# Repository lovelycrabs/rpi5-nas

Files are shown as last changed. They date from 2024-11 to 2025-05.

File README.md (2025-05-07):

## Installation
1.config system
```shell
git clone https://github.com/lovelycrabs/rpi5-nas.git
cd rpi5-nas
sudo chmod +x install.sh
sudo ./install.sh
sudo reboot
```
3.5寸4盘位RPI5_NAS_H4需要修改/boot/firmware/config.txt,该版本的风扇支持二线、三线、四线通用风扇、pwm风扇的周期改成20000000ns即频率为50hz
sudo nano /boot/firmware/config.txt
```shell
dtoverlay=pwm-fan-lm75,period=20000000
```
[overlay配置说明](boot/firmware/overlays)

可以通过下面命令查看系统功率
```shell
cat /sys/class/i2c-adapter/i2c-1/1-0040/hwmon/hwmon*/power1_input
```

查看输入电压
```shell
cat /sys/class/i2c-adapter/i2c-1/1-0040/hwmon/hwmon*/in1_input
```

查看lm75温度
```shell
cat /sys/class/i2c-adapter/i2c-1/1-0048/hwmon/hwmon*/temp1_input
```

2.install spi oled service
```shell
cd rpi5-nas/utils/display
sudo ./install.sh
```

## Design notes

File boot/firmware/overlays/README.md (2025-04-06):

## overlays配置
### 1，pwm-fan 配置
dts编译：
```shell
dtc -I dts -O dtb -o pwm-fan-lm75.dtbo pwm-fan-lm75.dts
dtc -I dts -O dtb -o pwm-fan-cpu.dtbo pwm-fan-cpu.dts
sudo cp pwm-fan-lm75.dtbo /boot/firmware/overlays
sudo cp pwm-fan-cpu.dtbo /boot/firmware/overlays
```
pwm-fan-lm75 为根据背板的温度传感器温度进行风扇调速

pwm-fan-cpu  根据cpu温度对风扇进行调速， 如果使用cpu进行调速，树莓派的3p风扇会无法动态调速。

配置：
编辑 /boot/firmware/config.txt

追加一下内容：

dtoverlay=pwm-fan-lm75,period=25000,hot_temp=40000,vhot_tem=60000

period:周期单位ns,25000ns,频率freq=1000000000/25000=40000hz

hot_temp风扇启转温度，40000为40摄氏度

vhot_temp:高温，高温pwm占空比从120/255到1

critical_temp:零界温度，超过该温度系统将自动关机，默认65000

如果想根据cpu温度调节风扇的速度可以改成

dtoverlay=pwm-fan-cpu

### 2,PCIE配置
拷贝 pciex1-compat-pi5.dtbo 到 /boot/firmware/overlays

编辑 /boot/firmware/config.txt 并添加一下内容

dtparam=pciex1_gen=3

dtoverlay=pciex1-compat-pi5,no-mip

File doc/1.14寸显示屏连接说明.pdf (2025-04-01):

## 1.14 寸 spi ips 显示屏连接说明

1. 显示屏

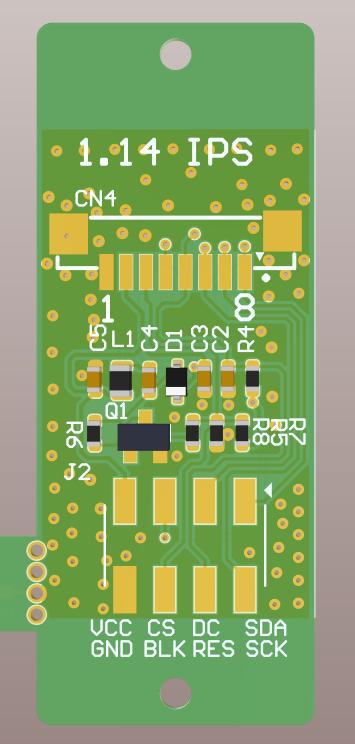
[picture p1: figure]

主控 ST7789V

2. 树莓派 5 40P GPIO

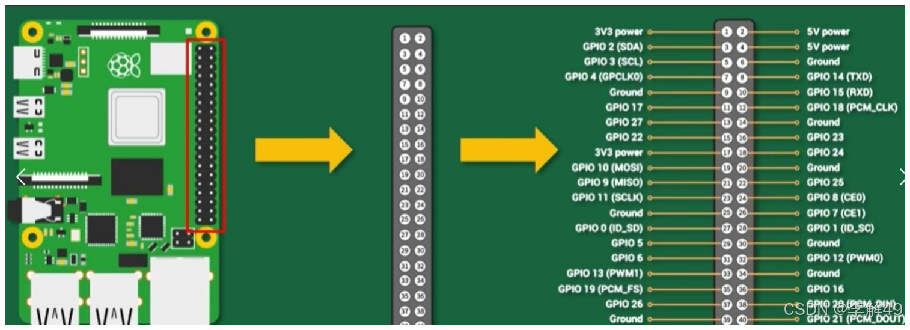
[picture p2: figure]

3.连接说明

引脚 | 功能 | 说明 | 电平 | 树莓派引脚
1 | GND | | | 物理引脚 6、14、 20、25、39
2 | VCC | 电源输入 | 3.3V | 物理引脚 1、17
3 | BLK | 背光，高电平有 效，支持 pwm 调 光 | 3.3V | 33：GPIO13
4 | CS | SPI 使能 | 3.3V | 24：GPIO08
5 | RESET | 复位 | 3.3V | 18：GPIO24
6 | D/C | 数据/命令 | 3.3V | 16：GPIO23
7 | SCK | spi 时钟 | 3.3V | 23：GPIO11
8 | SDA | SPI_MOSI | 3.3V | 19:GPIO10

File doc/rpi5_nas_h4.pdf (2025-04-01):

## 一、产品规格

## 规格说明

产品名称 | RPI5_NAS_H4
主控芯片 | ASM1064
输入接口 | 16P 0.5mm 排线，PCIE3.0 1X
SATA | 4*SATA 6Gbps
SATA 口间距 | 18mm
硬盘规格 | 支持 3.5 寸 SATA 硬盘
扩展功能 | LM75 温度传感器。 2X4 线风扇，PWM 调速，配合 LM75 可实现温控风扇 调速。 内置 INA226 功率传感器，可实时获取整体运行功耗。 每个硬盘有两个 led 灯，一个为状态灯、另一个为活 动指示灯。
供电 | 输入：DC 12V 普通 2.5 寸硬盘建议 5A 60W 以上电源； 企业级硬盘建议 6A 72W 以上电源。 输出：1 路 5V 5A ，用于给主板供电
产品尺寸 | 100mm*80mm
特性 | 通过 16P FPC 线连接，较少线材连接，提升空间利用 率。

## 二、接口说明

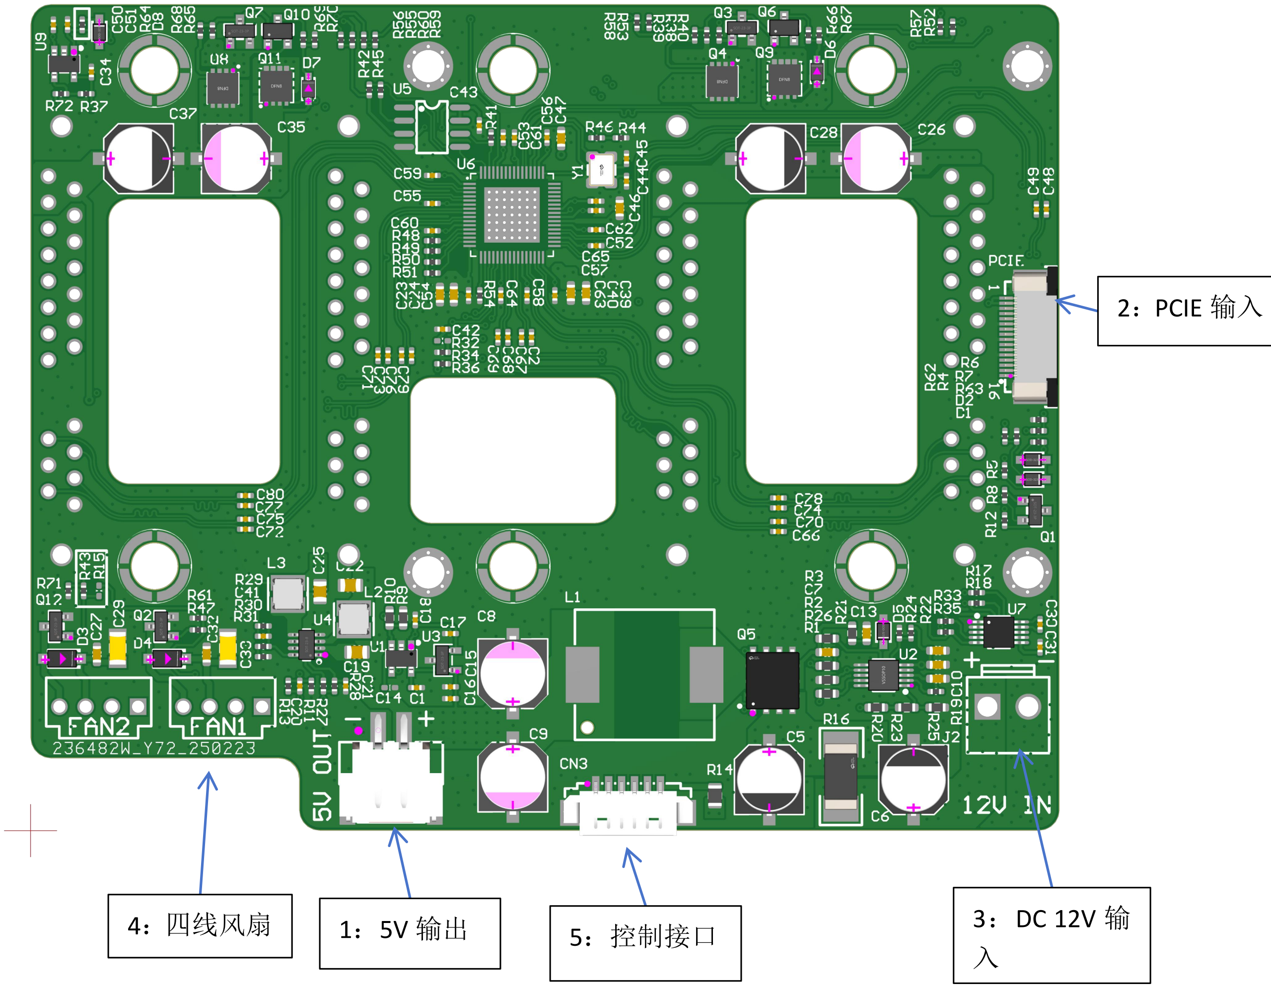
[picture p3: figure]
2：PCIE 输入; 4：四线风扇; 5：控制接口

1：5V 输出接口
Xh2.54 2p 接口，最高支持 5A 输出电流
1 | 5V+
2 | 5V- 2：PCIE 输入

FPC 24p 0.5mm 排线, PCIE 2X 输入
1 | 5V 输入
2 | 5V 输入
3 | GND
4 | REFCLK_P
5 | REFCLK_N

6 | GND
7 | PCIE_RX0_P
8 | PCIE_RX0_N
9 | GND
10 | PCIE_TX0_P
11 | PCIE_TX0_N
12 | GND
13 | PCIE_PWR_EN 电源是能引脚高电平有效 | 3.3V
14 | PCIE_DET_WAKE | 3.3V
15 | PCIE_CLKREQ_N | 3.3V
16 | PCIE_RST_B (PERST#) | 3.3V

3：DC 12V 输入
Xh3.96 2p 接口
1 | 12V+
2 | 12V- 4：4 线风扇接口

12V 4 线风扇 h2510 4p 接口， 只有当 PCIE_PWR_EN 为高电平才会有输出
PWM 调速 | 1 | 12V- 2 12V+
| 3 | NC
| 4 | NC

5：控制接口
风扇控制、I2C 接口，LM75、INA226 采集 LM75 I2C 地址：0x48
INA226 I2C 地址：0x40
从上到下 | 1 | 3.3V
| 2 | FAN_PWM 风扇 PWM 输入 | 3.3v
| 3 | NC | 3
| 4 | I2C_SDA 已接上拉电阻 | 3.3v
| 5 | I2C_SCL 已接上拉电阻 | 3.3v
| 6 | GND

## 三、尺寸说明

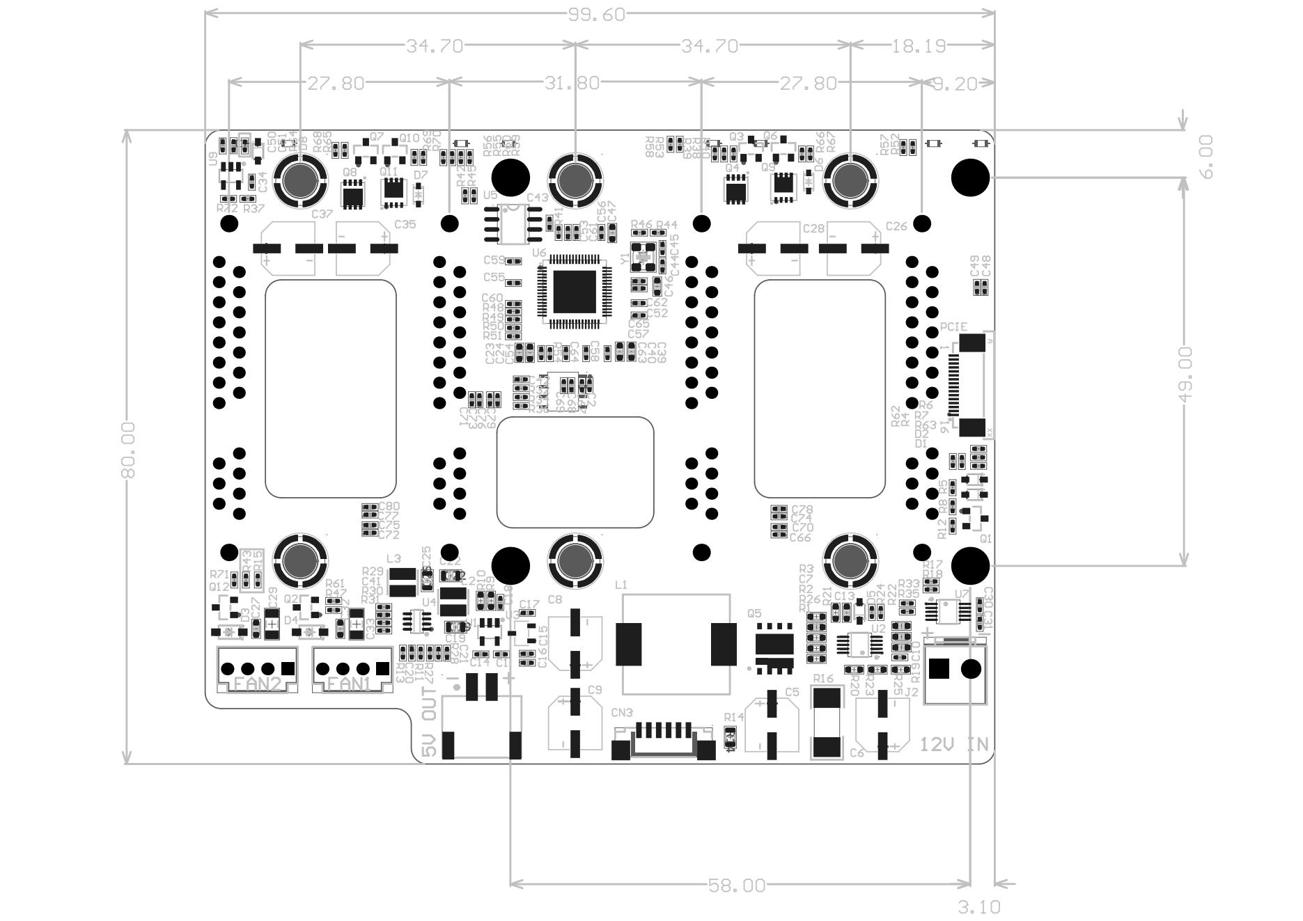
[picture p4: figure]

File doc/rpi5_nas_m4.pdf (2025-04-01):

## 一、产品规格

## 规格说明

产品名称 | RPI5_NAS_M4
主控芯片 | ASM1064
输入接口 | 16P 0.5mm 排线，PCIE3.0 1X
SATA | 4*SATA 6Gbps
SATA 口间距 | 18mm
硬盘规格 | 支持 2.5 寸 7mm、9.5mm、15mm 硬盘
扩展功能 | LM75 温度传感器。 4 线风扇，PWM 调速，配合 LM75 可实现温控风扇调 速。 内置 INA226 功率传感器，可实时获取整体运行功耗。 每个硬盘有两个 led 灯，一个为状态灯、另一个为活 动指示灯。
供电 | 输入：DC 12V 普通 2.5 寸硬盘建议 2A 24W 以上电源； 企业级硬盘建议 4A 48W 以上电源。 输出：1 路 5V 5A ，用于给主板供电
产品尺寸 | 72mm*75mm
特性 | 通过 16P FPC 线连接，较少线材连接，提升空间利用 率。

## 二、接口说明

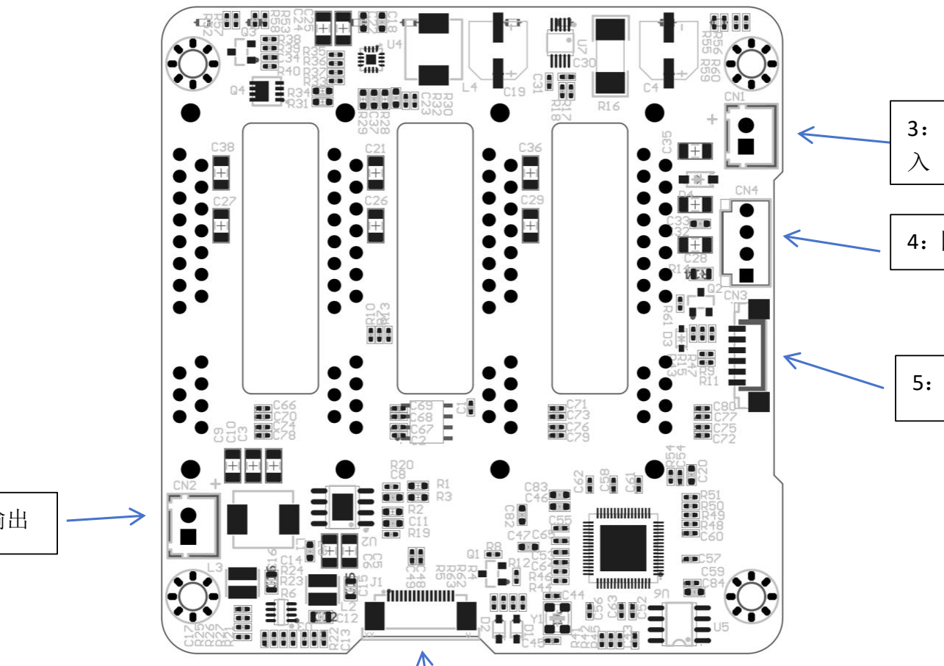
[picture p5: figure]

1：5V 输出接口
Xh2.54 2p 接口，最高支持 5A 输出电流
从上到下 | 1 | 5V+
2 | 5V- 2：PCIE 输入

FPC 24p 0.5mm 排线, PCIE 2X 输入
从左到右 | 1 | 5V 输入
| 2 | 5V 输入
| 3 | GND
| 4 | REFCLK_P
| 5 | REFCLK_N
| 6 | GND
| 7 | PCIE_RX0_P
| 8 | PCIE_RX0_N
| 9 | GND

1：5V 输出

2：PCIE 输入

3：DC 12V 输

4：四线风扇

5：控制接口

10 | PCIE_TX0_P
11 | PCIE_TX0_N
12 | GND
13 | PCIE_PWR_EN 电源是能引脚高电平有效 | 3.3V
14 | PCIE_DET_WAKE | 3.3V
15 | PCIE_CLKREQ_N | 3.3V
16 | PCIE_RST_B (PERST#) | 3.3V

3：DC 12V 输入
Xh2.54 2p 接口
从上到下 | 1 | 12V+
2 | 12V- 4：4 线风扇接口

12V 4 线风扇 XH2.54 4p 接口， 只有当 PCIE_PWR_EN 为高电平才会有输出
从上到下 | 1 | GND
| 2 | 12V
| 3 | FG
| 4 | PWM

5：控制接口
风扇控制、I2C 接口，LM75、INA226 采集 LM75 I2C 地址：0x48
INA226 I2C 地址：0x40
从上到下 | 1 | 3.3V
| 2 | FAN_PWM 风扇 PWM 输入 | 3.3v
| 3 | FAN_FG 风扇风速反馈 | 3.3v
| 4 | I2C_SDA 已接上拉电阻 | 3.3v
| 5 | I2C_SCL 已接上拉电阻 | 3.3v
| 6 | GND

## 三、尺寸说明

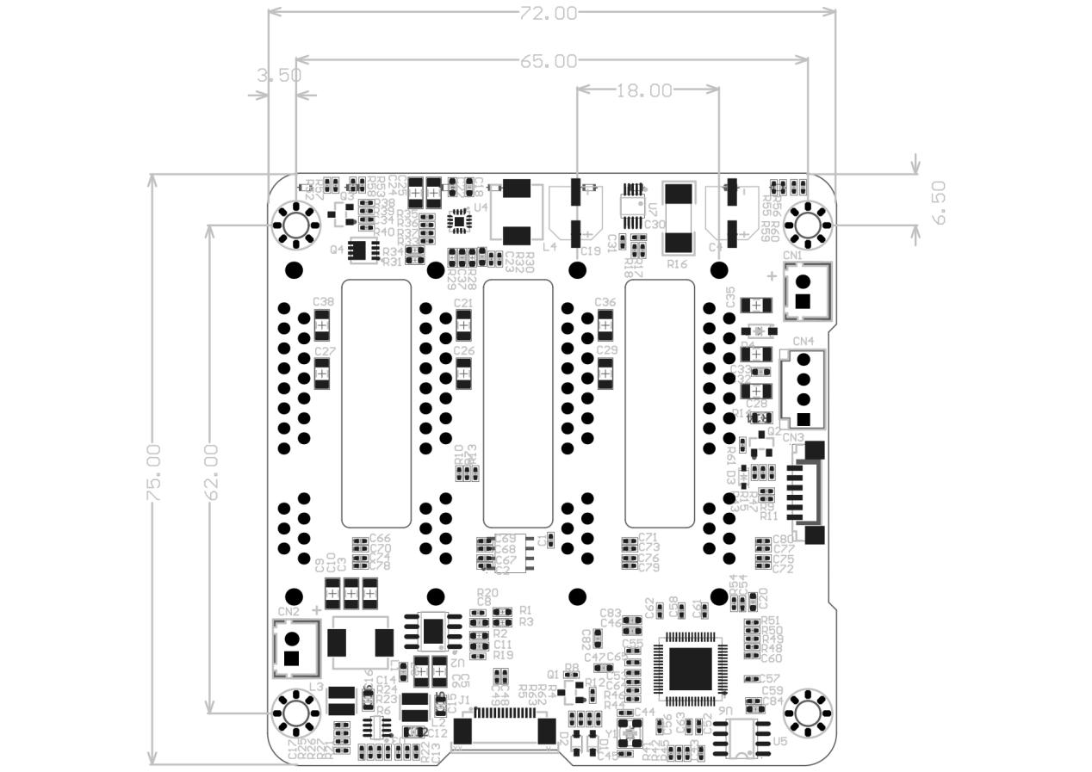
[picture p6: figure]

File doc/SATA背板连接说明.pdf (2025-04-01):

# SATA 背板连接说明

## 一、树莓派引脚


## 二、5V 5A 供电连接

1，5V+连接到树莓派 2、4 的 5V power 引脚 2，5V-连接到树莓派的 GND
注意：不要接反
线材尽量选用粗一点的线材

## 三、PCIE 线的连接

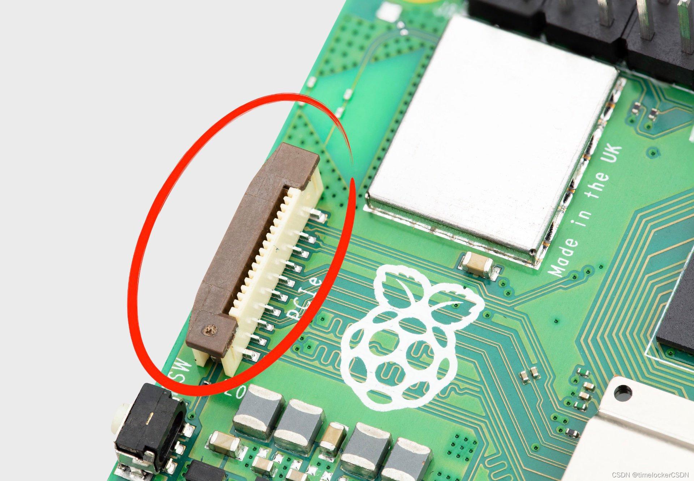
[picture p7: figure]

通过 0.5 16p FPC 线进行连接，PCIE 接口顶见官网

## 四、控制接口连接

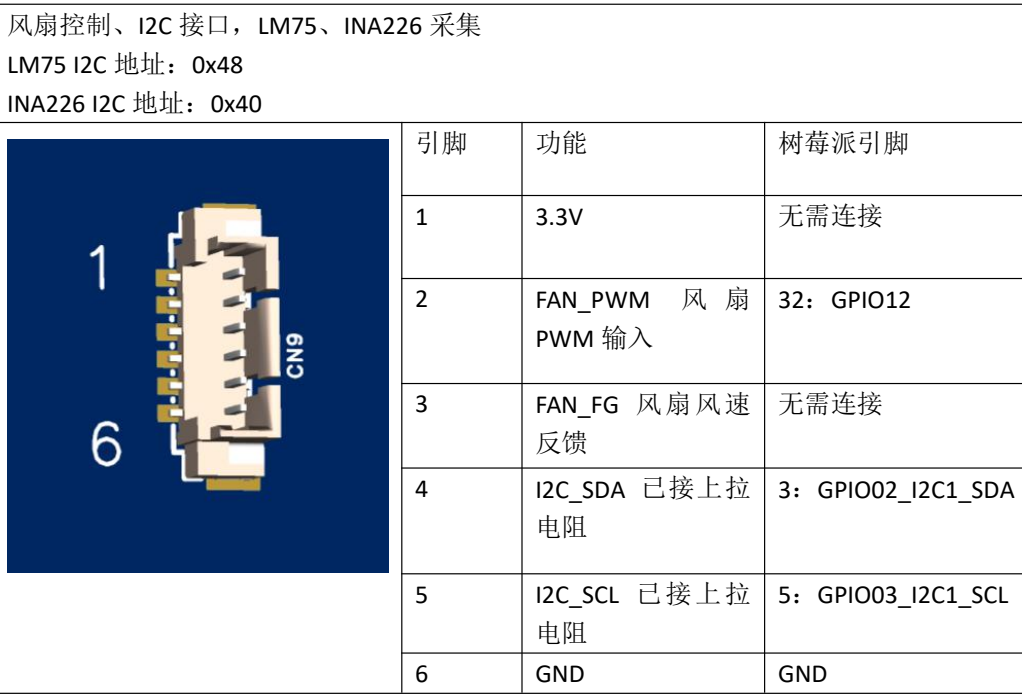
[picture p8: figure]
风扇控制、I2C 接口，LM75、INA226 采集 LM75 I2C 地址：0x48 INA226 I2C 地址：0x40; 树莓派引脚; 无需连接; FAN_PWM 风 扇 PWM 输入; 32：GPIO12; FAN_FG 风扇风速 反馈; I2C_SDA 已接上拉 电阻; 3：GPIO02_I2C1_SDA; I2C_SCL 已接上拉 电阻; 5：GPIO03_I2C1_SCL; GND

5：控制接口

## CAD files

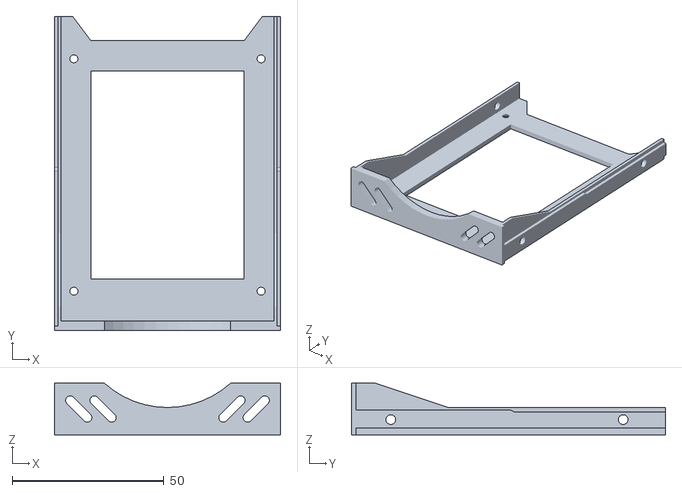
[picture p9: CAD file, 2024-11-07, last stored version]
stl/raspi_nas_hd.STL
74.5 x 103.6 x 17.0

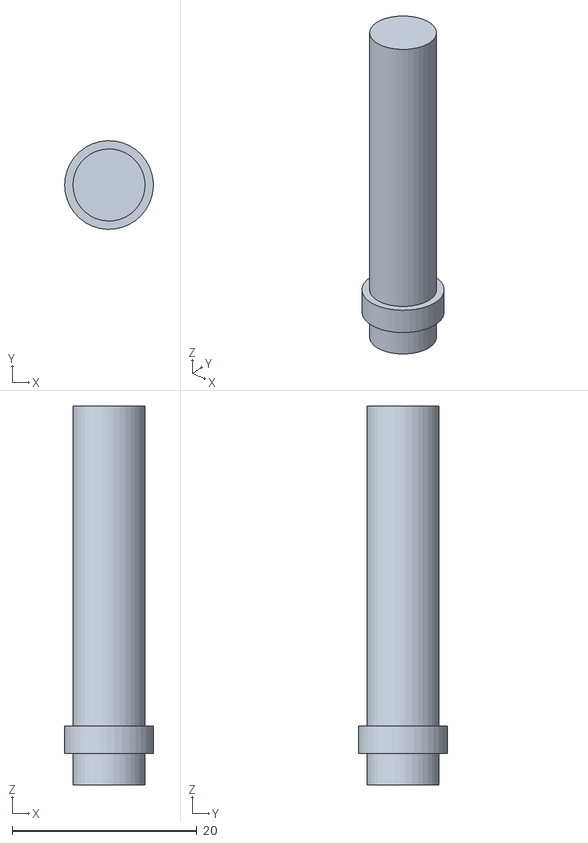
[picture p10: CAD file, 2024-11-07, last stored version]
stl/raspi_nas_btn.STL
9.60 x 9.59 x 41.0

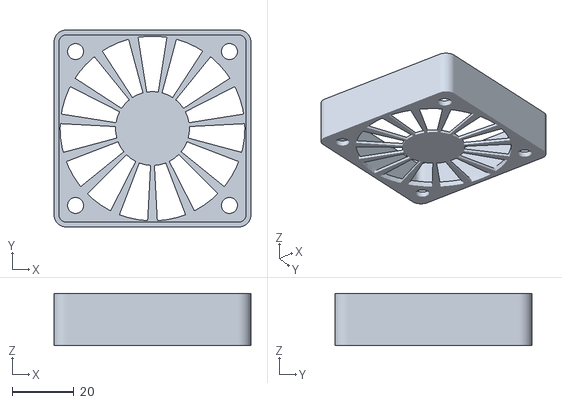
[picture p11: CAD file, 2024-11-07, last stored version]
stl/raspi_nas_fan.STL
64.0 x 64.0 x 17.0

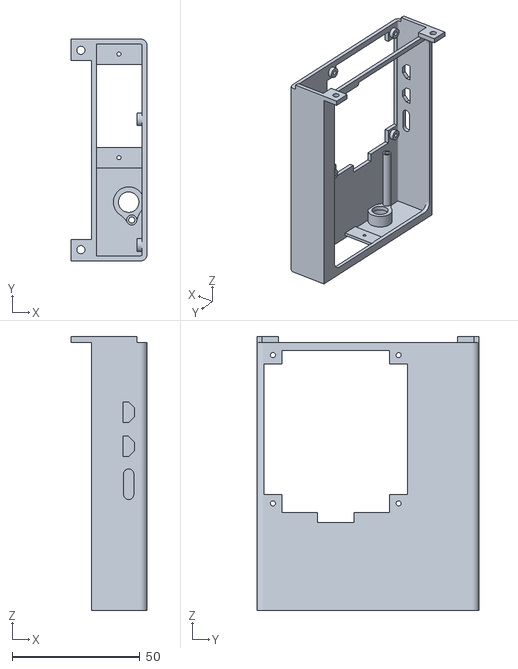
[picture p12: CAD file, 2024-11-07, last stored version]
stl/raspi_nas_board.STL
29.8 x 86.8 x 107.2

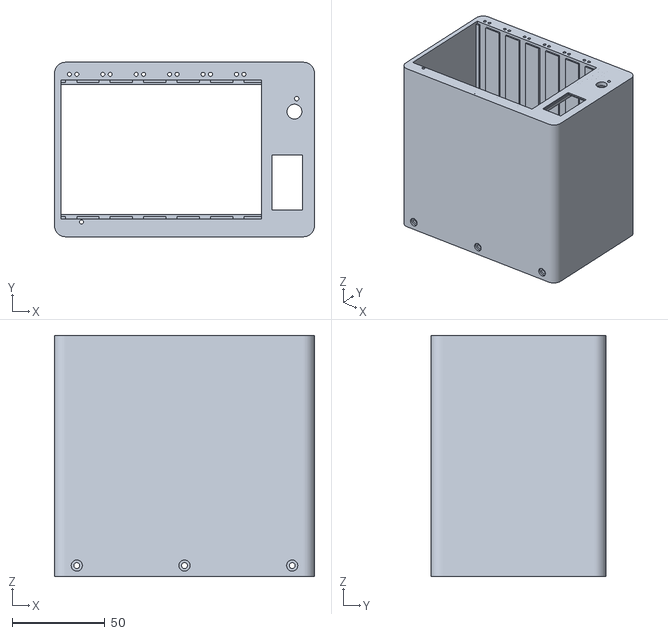
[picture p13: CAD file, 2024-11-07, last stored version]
stl/raspi_nas.STL
140.0 x 94.0 x 130.0

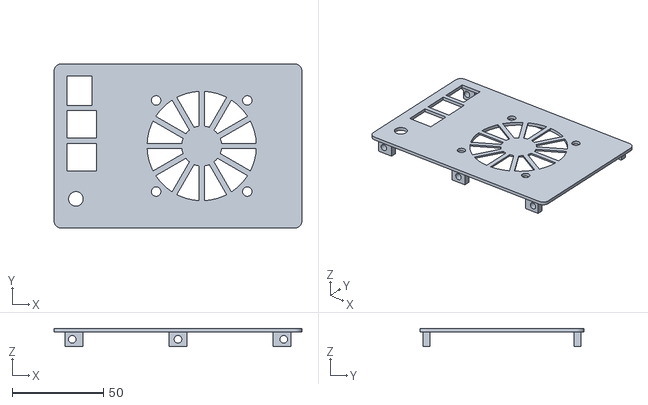
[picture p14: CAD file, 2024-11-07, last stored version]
stl/raspi_nas_b.STL
136.0 x 90.0 x 10.0

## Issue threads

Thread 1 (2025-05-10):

lm75 not found

MarcusTseng, 2025-05-10:
您好，我在上次您通知有修改更新之後還是無法恢復OLED顯示功能
今天留意到又有多次更新
在試過之後還是一樣的error log

`marcus@rpi5-nas:~ $ cd rpi5-nas/utils/display
marcus@rpi5-nas:~/rpi5-nas/utils/display $ sudo ./install.sh
.
Reading package lists... Done
Building dependency tree... Done
Reading state information... Done
python3-dev is already the newest version (3.11.2-1+b1).
libfreetype6-dev is already the newest version (2.12.1+dfsg-5+deb12u4).
libopenblas-dev is already the newest version (0.3.21+ds-4).
libjpeg-dev is already the newest version (1:2.1.5-2).
libopenjp2-7 is already the newest version (2.5.0-2+deb12u1).
The following packages were automatically installed and are no longer required:
  linux-headers-6.6.51+rpt-common-rpi linux-headers-6.6.51+rpt-rpi-2712 linux-headers-6.6.51+rpt-rpi-v8
  linux-image-6.6.51+rpt-rpi-2712 linux-image-6.6.51+rpt-rpi-v8 linux-kbuild-6.6.51+rpt
Use 'sudo apt autoremove' to remove them.
0 upgraded, 0 newly installed, 0 to remove and 0 not upgraded.
warning:device lm75 not found!
marcus@rpi5-nas:~/rpi5-nas/utils/display $`

lovelycrabs, 2025-05-11:
cat /sys/class/i2c-adapter/i2c-1/1-0048/hwmon/hwmon*/temp1_input
或
cat lm75_device_hwmon = '/sys/class/i2c-dev/i2c-1/device/1-0048/hwmon/hwmon*/temp1_input
看下有没有输出。
如果没有输出，再检查下config.txt有没有添加 “dtoverlay=pwm-fan-lm75”这行。

另外我又重新调整了一下显示程序，你可以再clone安装一下。

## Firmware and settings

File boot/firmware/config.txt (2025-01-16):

# For more options and information see
# http://rptl.io/configtxt
# Some settings may impact device functionality. See link above for details

# Uncomment some or all of these to enable the optional hardware interfaces
dtparam=i2c_arm=on
#dtparam=i2s=on
dtparam=spi=on

# Enable audio (loads snd_bcm2835)
dtparam=audio=on

# Additional overlays and parameters are documented
# /boot/firmware/overlays/README
dtoverlay=i2c-sensor,lm75,i2c1,addr=0x48

# Automatically load overlays for detected cameras
camera_auto_detect=1

# Automatically load overlays for detected DSI displays
display_auto_detect=1

# Automatically load initramfs files, if found
auto_initramfs=1

# Enable DRM VC4 V3D driver
dtoverlay=vc4-kms-v3d
max_framebuffers=2

# Don't have the firmware create an initial video= setting in cmdline.txt.
# Use the kernel's default instead.
disable_fw_kms_setup=1

# Run in 64-bit mode
arm_64bit=1

# Disable compensation for displays with overscan
disable_overscan=1

# Run as fast as firmware / board allows
arm_boost=1

[cm4]
# Enable host mode on the 2711 built-in XHCI USB controller.
# This line should be removed if the legacy DWC2 controller is required
# (e.g. for USB device mode) or if USB support is not required.
otg_mode=1

[cm5]
dtoverlay=dwc2,dr_mode=host

[all]
dtparam=pciex1_gen=3
dtoverlay=pciex1-compat-pi5,no-mip
#dtoverlay=pwm,pin=12,func=4,clock=20000
#dtoverlay=gpio-fan,gpiopin=12,temp=52000
dtoverlay=pwm-fan-lm75
dtoverlay=i2c-ina226
